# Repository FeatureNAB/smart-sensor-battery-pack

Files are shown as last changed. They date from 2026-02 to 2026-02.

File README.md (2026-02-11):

# Smart Sensor Battery Pack
This is the experimental battery charging PCB designed for my YouTube video. You can see the full build process, design theory, and assembly in the video below:

Watch the video (https://www.youtube.com/watch?v=-wEKOhVZ0NM)

### Please note: 
This board is currently missing a pull up resistor on the SCL/SDA lines - I will be adding this very soon. Software correction is possible using the XIAO pull-ups, so if you manufacture this board in its current form it will still work, it just makes the code a little more verbose. 

## ⚠️ Safety Warning
This board involves **Lithium-Ion battery charging**. 
*   This is an **experimental prototype** from a hobbyist. **I am not a professional engineer**. It has **not** been certified by safety agencies (UL, CE, etc.).
*   Lithium batteries can be dangerous if mishandled (risk of thermal runaway, fire, explosion, and serious injury).
*   **DO NOT leave this device unattended with a battery connected**
*   By using these files, you agree that you are solely responsible for verifying the safety of the circuit.

## License & Liability

### 1. Non-Commercial Use Only
This project is shared under the [Creative Commons Attribution-NonCommercial-ShareAlike 4.0 International](https://creativecommons.org/licenses/by-nc-sa/4.0/) license.
*  **You are free to:** Download, modify, and build this for personal use or learning.
*  **You may NOT:** Sell this board, use it in a product you sell, or use these files for any commercial purpose.
*  If you modify and share this design, you must share it under this same license.

### 2. No Liability (Disclaimer)
These files are provided "As Is" for educational purposes ONLY. I am sharing my personal project notes. **I accept no liability for any damage, injury, or loss** that occurs from the use or assembly of these files. Use them at your own risk.

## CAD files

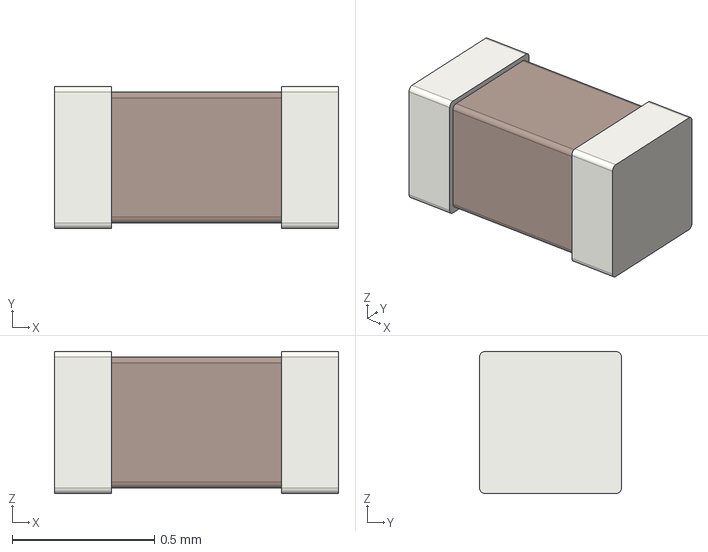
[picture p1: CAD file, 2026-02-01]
3d_models/C_0402_1005Metric.step
1.00 x 0.5 x 0.5 mm

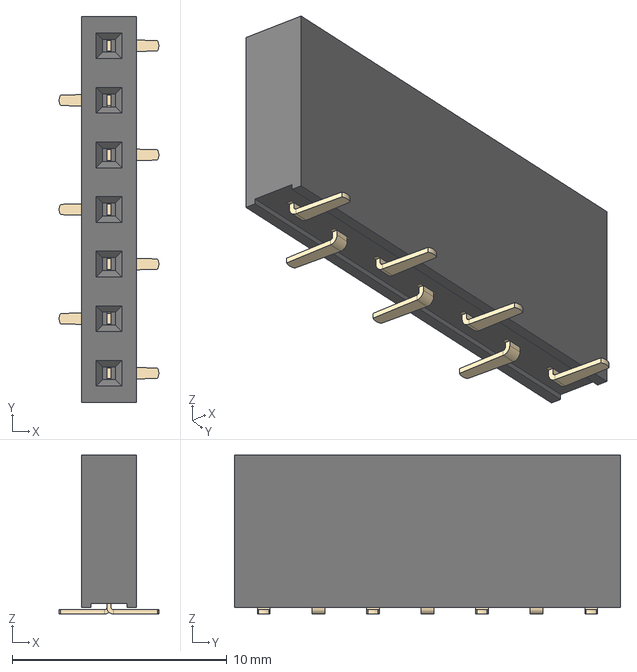
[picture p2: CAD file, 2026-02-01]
3d_models/PinSocket_1x07_P2.54mm_Vertical_SMD_Pin1Right.step
4.64 x 18.0 x 7.40 mm

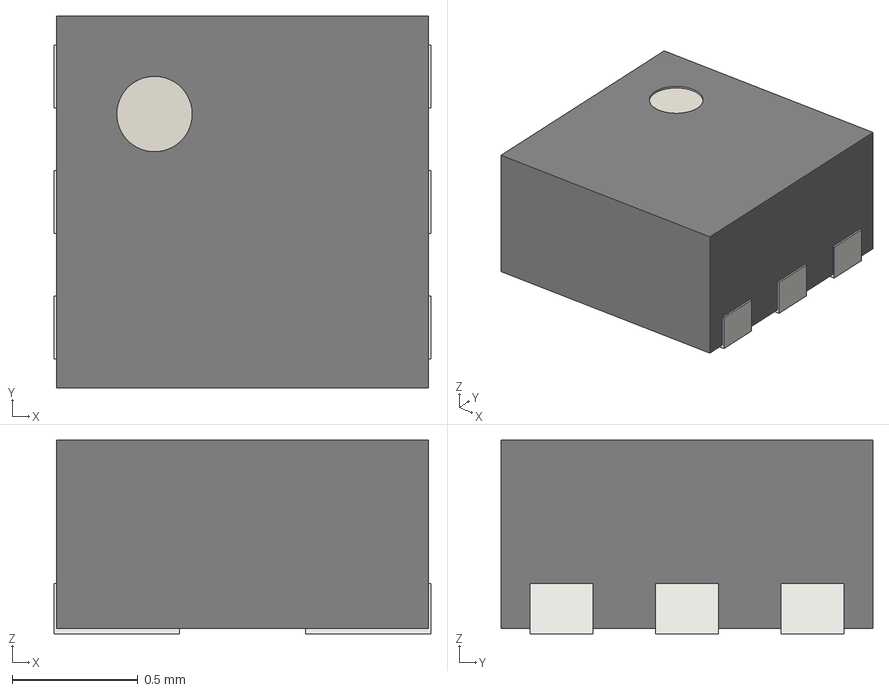
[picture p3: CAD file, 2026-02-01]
3d_models/WSON-6_1.5x1.5mm_P0.5mm.step
1.50 x 1.48 x 0.77 mm

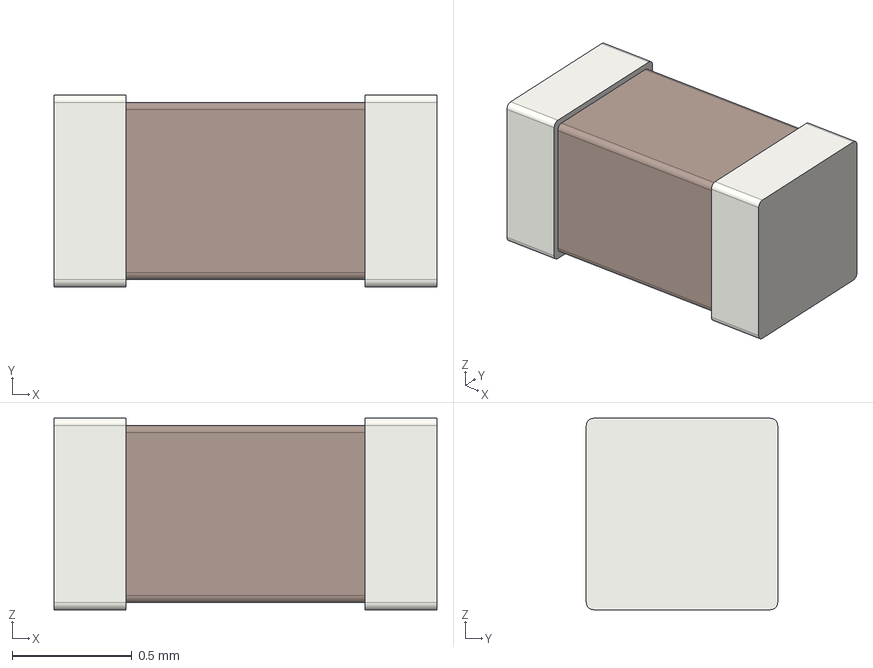
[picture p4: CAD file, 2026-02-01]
3d_models/C_0603_1608Metric.step
1.60 x 0.8 x 0.8 mm

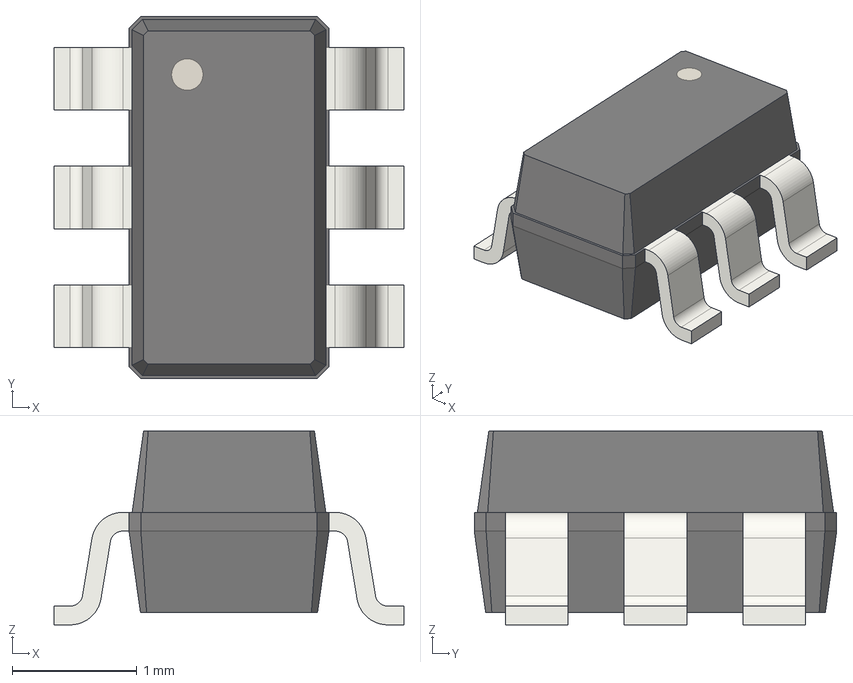
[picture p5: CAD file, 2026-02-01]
3d_models/SOT-23-6.step
2.80 x 2.90 x 1.55 mm

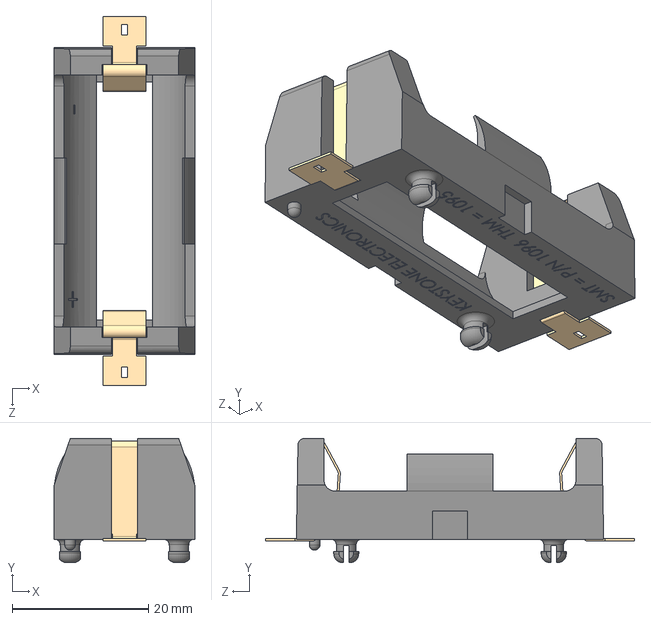
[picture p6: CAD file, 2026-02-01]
3d_models/1096.step
20.7 x 18.3 x 54.2 mm

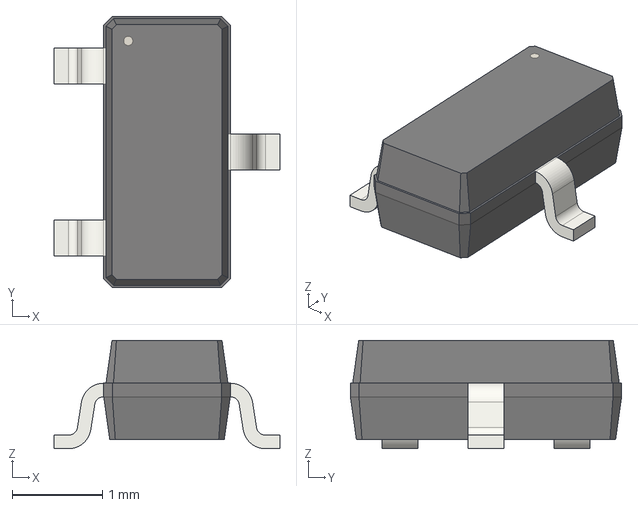
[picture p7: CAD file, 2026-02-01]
3d_models/SOT-23.step
2.50 x 3.00 x 1.20 mm

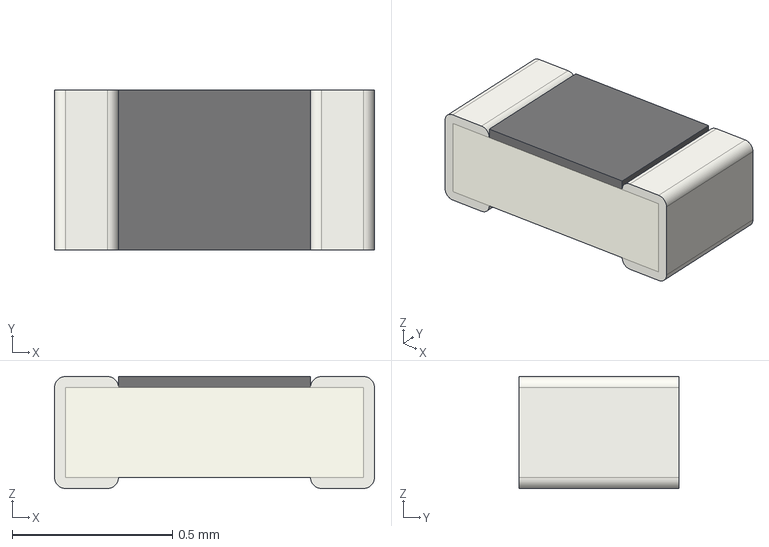
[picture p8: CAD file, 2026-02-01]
3d_models/R_0402_1005Metric.step
1.00 x 0.5 x 0.35 mm

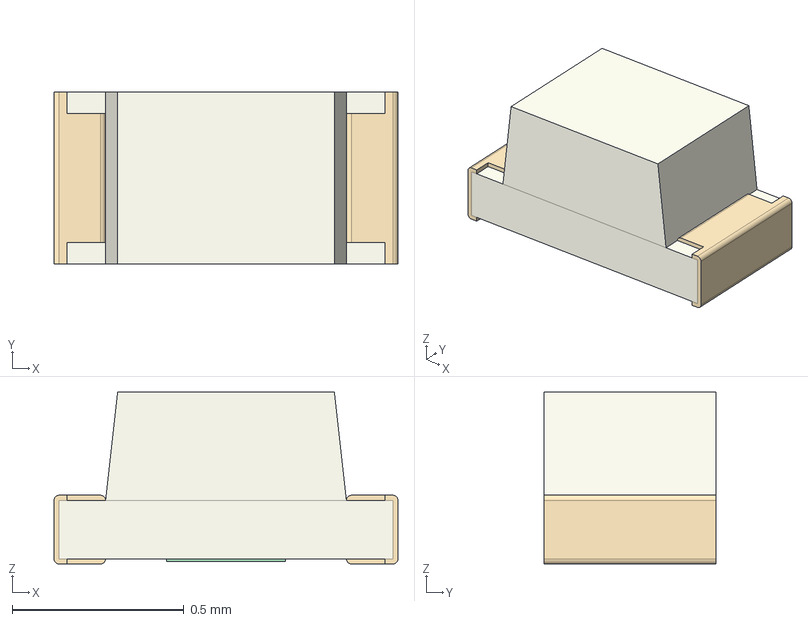
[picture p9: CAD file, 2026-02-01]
3d_models/LED_0402_1005Metric.step
1.00 x 0.5 x 0.5 mm

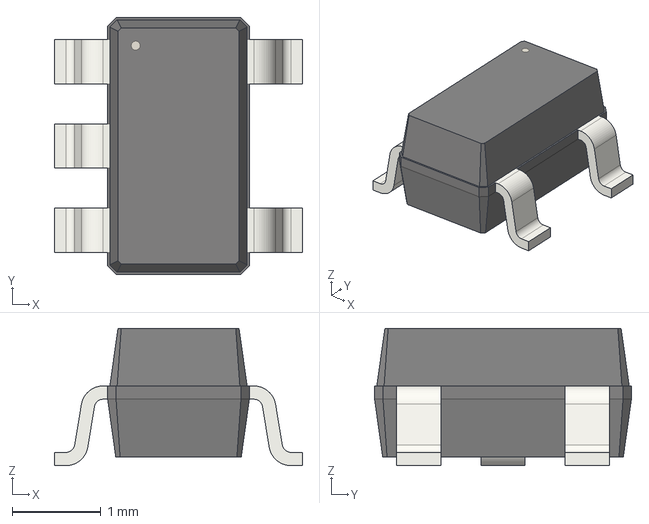
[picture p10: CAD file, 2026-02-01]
3d_models/SOT-23-5.step
2.80 x 2.90 x 1.55 mm

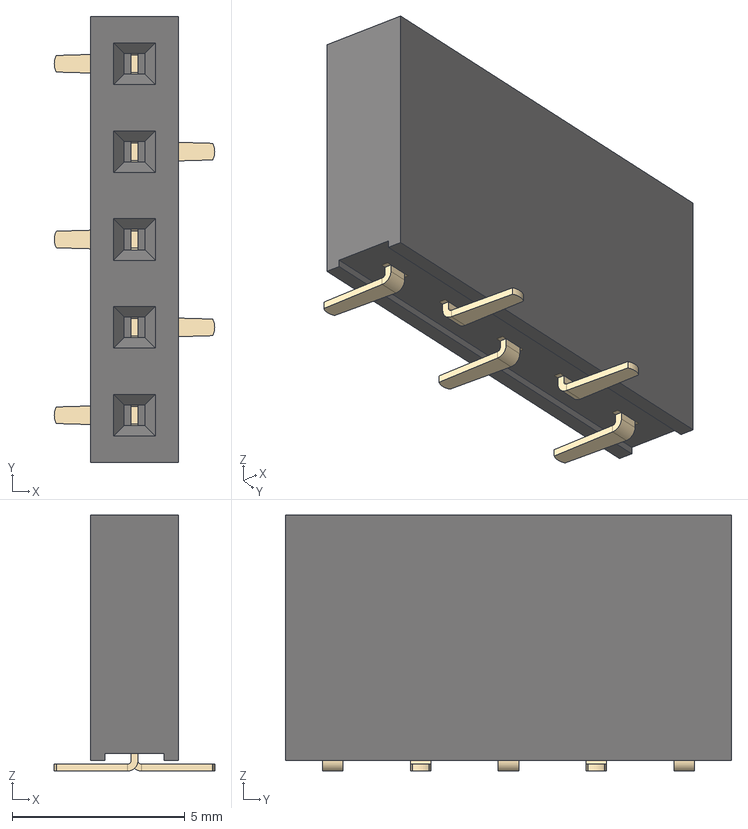
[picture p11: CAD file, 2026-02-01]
3d_models/PinSocket_1x05_P2.54mm_Vertical_SMD_Pin1Left.step
4.64 x 12.9 x 7.40 mm

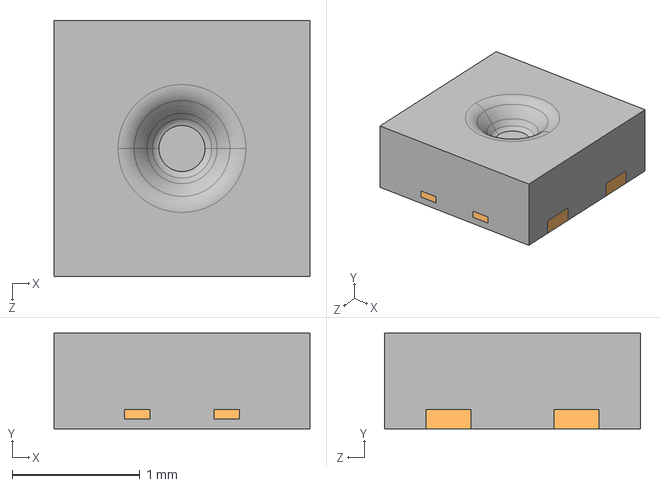
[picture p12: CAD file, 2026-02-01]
3d_models/SHTC3.step
2.00 x 0.75 x 2.00 mm

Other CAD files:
3d_models/PinSocket_1x07_P2.54mm_Vertical_SMD_Pin1Left.step

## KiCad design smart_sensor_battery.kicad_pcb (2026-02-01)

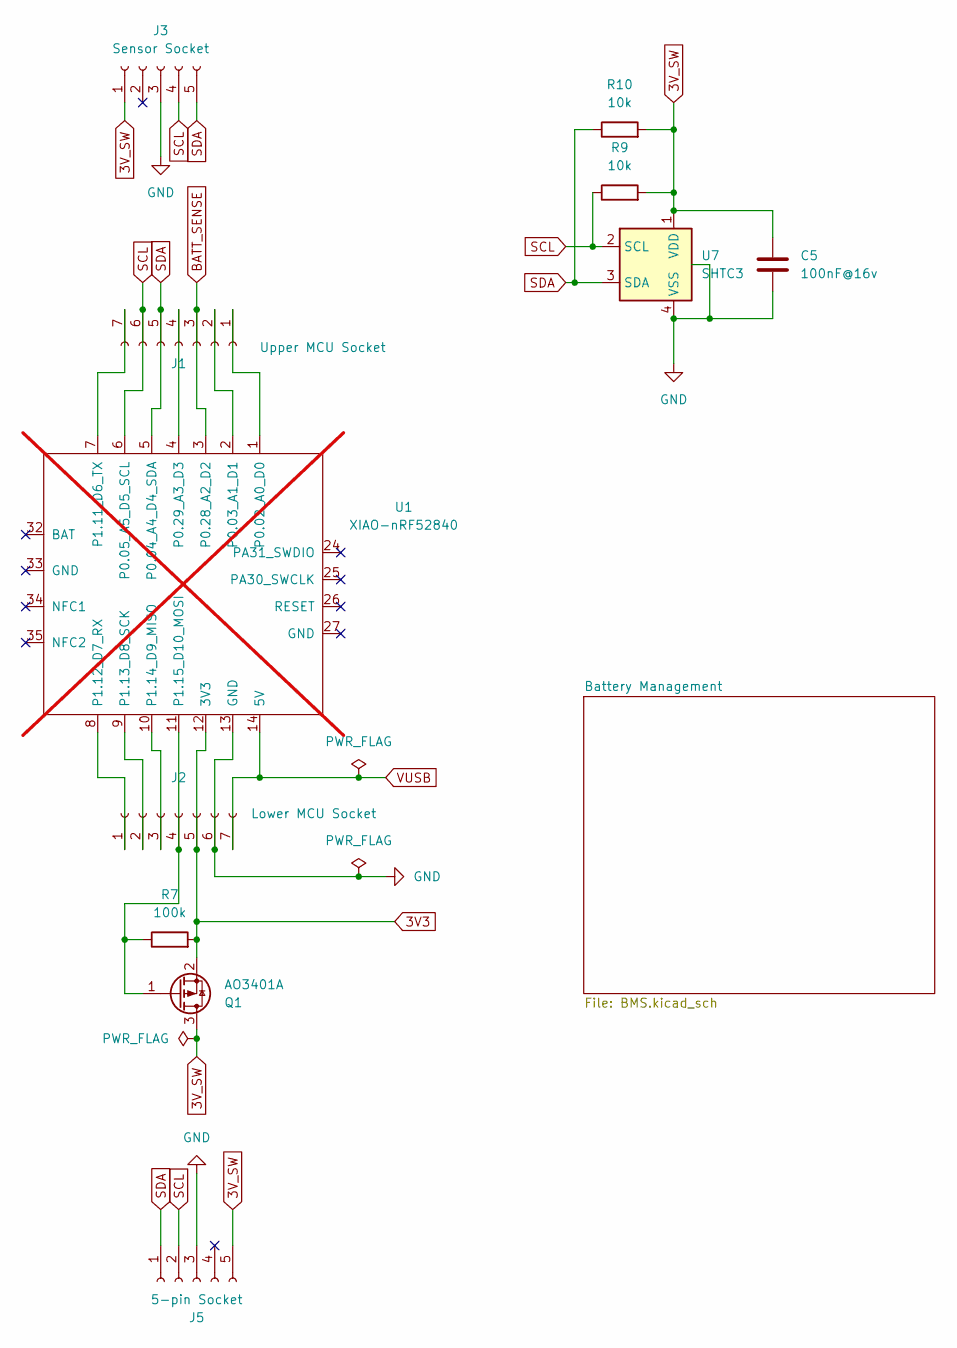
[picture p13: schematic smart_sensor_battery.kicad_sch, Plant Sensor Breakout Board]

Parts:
C5: 100nF@16v; C_0402_1005Metric; LCSC Part no. C1525
J1: Upper MCU Socket; PinSocket_1x07_P2.54mm_Vertical_SMD_Pin1Left; LCSC Part no. C42379199
J2: Lower MCU Socket; PinSocket_1x07_P2.54mm_Vertical_SMD_Pin1Right; LCSC Part no. C42379199
J3: Sensor Socket; PinSocket_1x07_P2.54mm_Vertical_SMD_Pin1Right; LCSC Part no. C42379199
J5: 5-pin Socket; PinSocket_1x05_P2.54mm_Vertical_SMD_Pin1Left; LCSC Part no. C42379198
Q1: AO3401A; SOT-23; LCSC Part no. C15127
R7: 100k; R_0402_1005Metric; LCSC Part no. C25530
R9, R10: 10k; R_0402_1005Metric; LCSC Part no. C25744
U1: XIAO-nRF52840; XIAO-nRF52840-SMD; not fitted
U7: SHTC3; Sensirion_DFN-4-1EP_2x2mm_P1mm_EP0.7x1.6mm

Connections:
3V3: J2.5, Q1.2 (S), R7.2, U1.12 (3V3); also elsewhere on the board
3V_SW: C5.1, J3.1, J5.5, Q1.3 (D), R9.2, R10.2, U7.1 (VDD)
BATT_SENSE: J1.3, U1.3 (P0.28_A2_D2); also elsewhere on the board
GND: C5.2, J2.6, J3.3, J5.3, U1.13 (GND), U7.4 (VSS), U7.5 (GND_(centre_pad)); also elsewhere on the board
unnamed: J1.1, U1.1 (P0.02_A0_D0)
unnamed: J1.2, U1.2 (P0.03_A1_D1)
unnamed: J1.4, U1.4 (P0.29_A3_D3)
unnamed: J1.7, U1.7 (P1.11_D6_TX)
unnamed: J2.1, U1.8 (P1.12_D7_RX)
unnamed: J2.2, U1.9 (P1.13_D8_SCK)
unnamed: J2.3, U1.10 (P1.14_D9_MISO)
unnamed: J2.4, Q1.1 (G), R7.1, U1.11 (P1.15_D10_MOSI)
SCL: J1.6, J3.4, J5.2, R9.1, U1.6 (P0.05_A5_D5_SCL), U7.2 (SCL)
SDA: J1.5, J3.5, J5.1, R10.1, U1.5 (P0.04_A4_D4_SDA), U7.3 (SDA)
VUSB: J2.7, U1.14 (5V); also elsewhere on the board

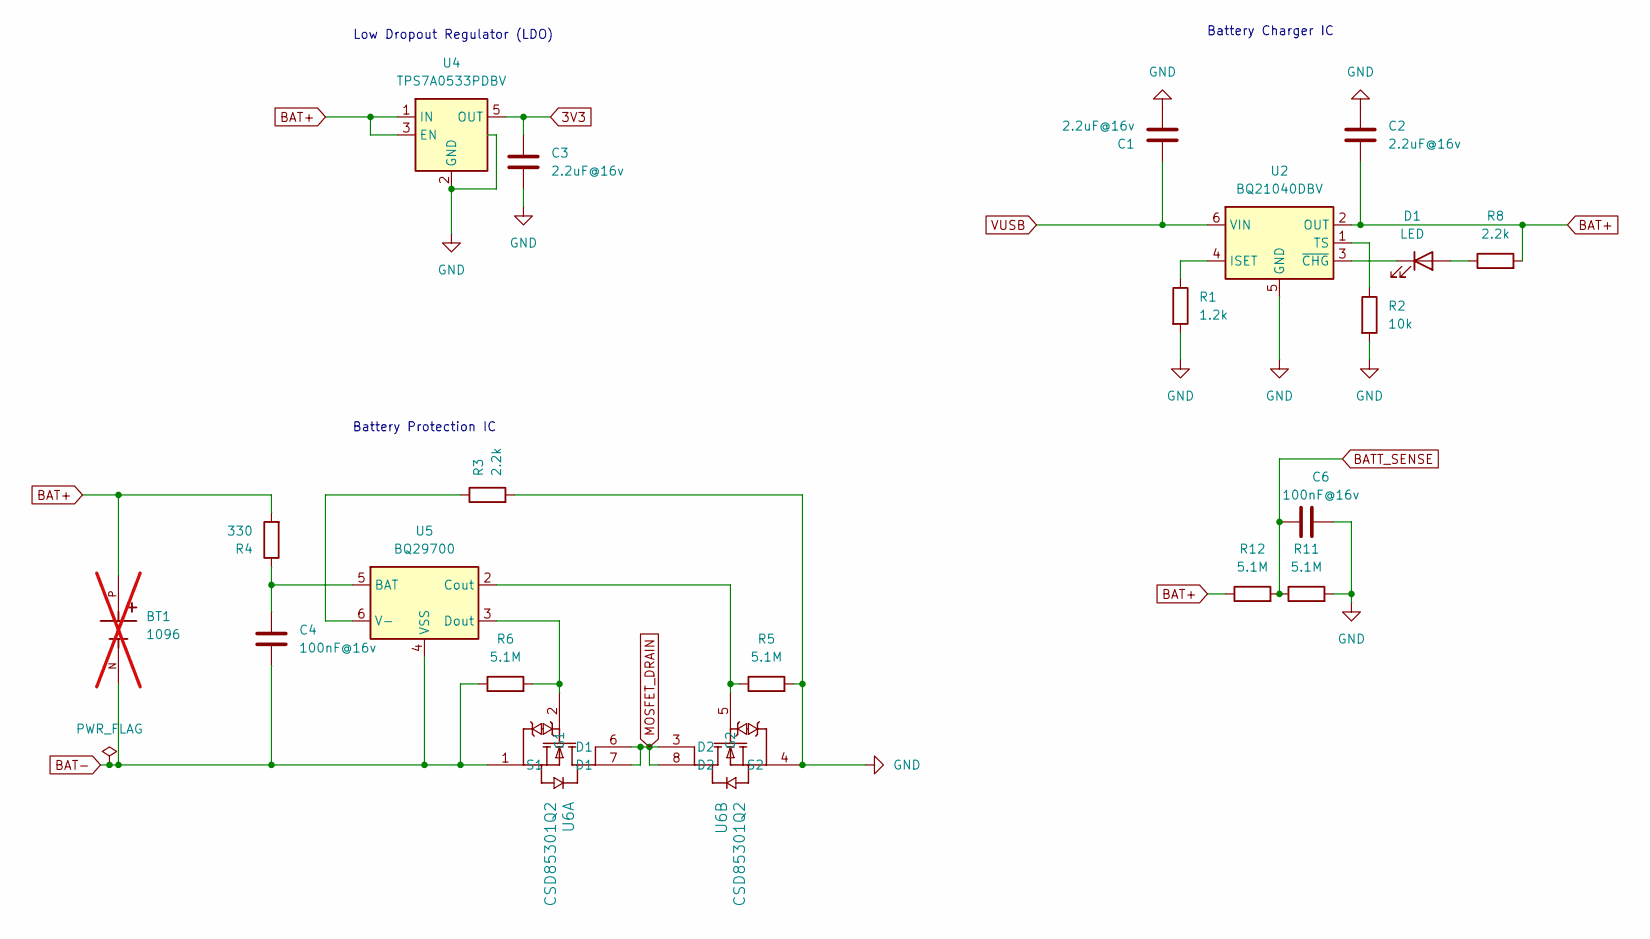
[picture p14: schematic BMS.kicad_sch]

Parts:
BT1: 1096; BAT_1096; PARTREV A; not fitted
C1, C2, C3: 2.2uF@16v; C_0603_1608Metric; LCSC Part no. C23630
C4, C6: 100nF@16v; C_0402_1005Metric; LCSC Part no. C1525
D1: LED; LED_0402_1005Metric; LCSC Part no. C74339
R1: 1.2k; R_0402_1005Metric; LCSC Part no. C25862
R2: 10k; R_0402_1005Metric; LCSC Part no. C25744
R3, R8: 2.2k; R_0402_1005Metric; LCSC Part no. C25879
R4: 330; R_0402_1005Metric; LCSC Part no. C25104
R5, R6, R11, R12: 5.1M; R_0402_1005Metric; LCSC Part no. C26092
U2: BQ21040DBV; SOT-23-6; LCSC Part no. C202311
U4: TPS7A0533PDBV; SOT-23-5; LCSC Part no. C493453
U5: BQ29700; WSON-6_1.5x1.5mm_P0.5mm; LCSC Part no. C183096
U6: CSD85301Q2; LCSC Part no. C544396

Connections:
3V3: C3.1, U4.5 (OUT); also elsewhere on the board
BAT+: BT1.P, C2.1, R4.2, R8.2, R12.1, U2.2 (OUT), U4.1 (IN), U4.3 (EN)
BAT-: BT1.N, C4.2, R6.1, U5.4 (VSS), U6.1 (S1)
BATT_SENSE: C6.1, R11.1, R12.2; also elsewhere on the board
GND: C1.2, C2.2, C3.2, C6.2, R1.2, R2.2, R3.2, R5.2, R11.2, U2.5 (GND), U4.2 (GND), U4.4 (NC_(GND)), U6.4 (S2); also elsewhere on the board
MOSFET_DRAIN: U6.3 (D2), U6.6 (D1), U6.7 (D1), U6.8 (D2)
unnamed: D1.2 (A), R8.1
unnamed: D1.1 (K), U2.3 (~CHG)
unnamed: R1.1, U2.4 (ISET)
unnamed: R2.1, U2.1 (TS)
unnamed: C4.1, R4.1, U5.5 (BAT)
unnamed: R5.1, U5.2 (Cout), U6.5 (G2)
unnamed: R6.2, U5.3 (Dout), U6.2 (G1)
unnamed: R3.1, U5.6 (V-)
VUSB: C1.1, U2.6 (VIN); also elsewhere on the board

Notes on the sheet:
Battery Protection IC
Battery Charger IC
Low Dropout Regulator (LDO)

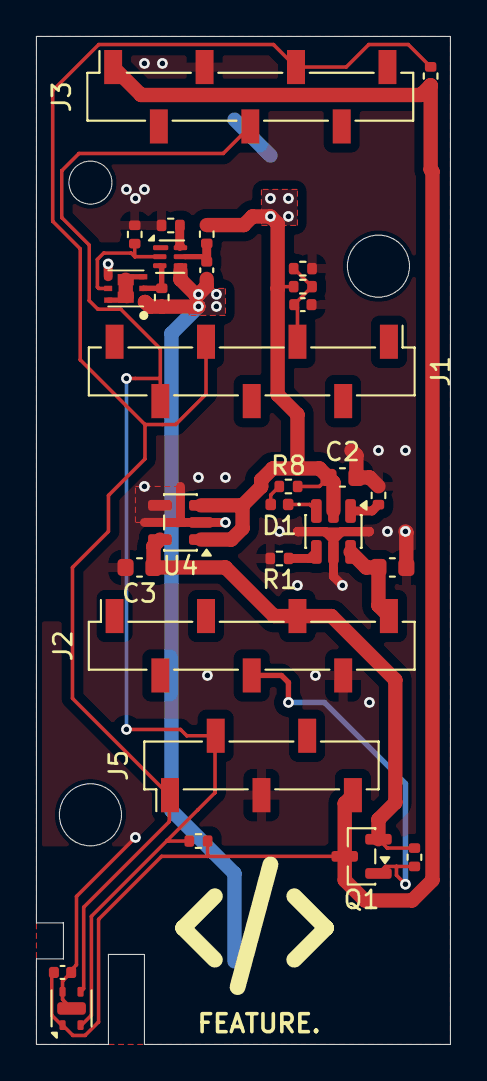
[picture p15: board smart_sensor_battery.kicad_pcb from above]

Board: 2 copper layers, 23.0 x 56.0 mm, 30 parts (1 on the bottom side), 19 nets.

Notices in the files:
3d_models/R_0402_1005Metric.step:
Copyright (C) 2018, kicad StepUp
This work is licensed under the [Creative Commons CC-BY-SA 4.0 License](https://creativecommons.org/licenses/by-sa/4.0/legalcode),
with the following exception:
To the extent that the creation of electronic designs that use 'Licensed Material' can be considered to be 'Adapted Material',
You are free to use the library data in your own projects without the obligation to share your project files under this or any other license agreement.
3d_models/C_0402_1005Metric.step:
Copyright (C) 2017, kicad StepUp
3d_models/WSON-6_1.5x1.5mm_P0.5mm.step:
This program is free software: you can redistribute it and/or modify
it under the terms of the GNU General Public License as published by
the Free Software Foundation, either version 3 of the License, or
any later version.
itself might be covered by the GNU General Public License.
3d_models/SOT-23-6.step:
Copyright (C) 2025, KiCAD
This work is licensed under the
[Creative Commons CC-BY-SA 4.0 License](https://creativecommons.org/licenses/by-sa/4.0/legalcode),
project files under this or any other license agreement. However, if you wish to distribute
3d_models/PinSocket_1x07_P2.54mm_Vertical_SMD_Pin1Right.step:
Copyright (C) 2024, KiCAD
